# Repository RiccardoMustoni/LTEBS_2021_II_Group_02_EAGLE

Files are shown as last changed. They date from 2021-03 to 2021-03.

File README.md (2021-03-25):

# LTEBS_2021_II_Group_02_EAGLE

### Final Version 
The aim of the project is to design a PCB embedding the PSoC 5LP micro-controller in order to evaluate its performance and to determine if such uC is suitable for the project. The PCB embeds the CY8CKIT-059 kit, which will be soldered on male jumpers, and other additional components required to coduct the proper testing. 

The project consists in the design of a schematic, a board, and a library containing the necessary components. Design rules are added according to the technical specifications reported in the manufacturer website MDSrl.

### Project Folder 
The folder contains the schematic ("Group_02.sch") and the board ("Group_02.brd") used to create the final PCB.

### Library Folder 
The folder contains the library ("Group_02_Library.lbr") for the components TCA9546A and TMUX1208 with footprints, symbols and devices. 

### Design Rules Folder 
The folder contains the design rules ("Group_02.dru") according to the technical info on the manufacturer website. 

### Contributors 

Mancini Giorgia,
Mustoni Riccardo

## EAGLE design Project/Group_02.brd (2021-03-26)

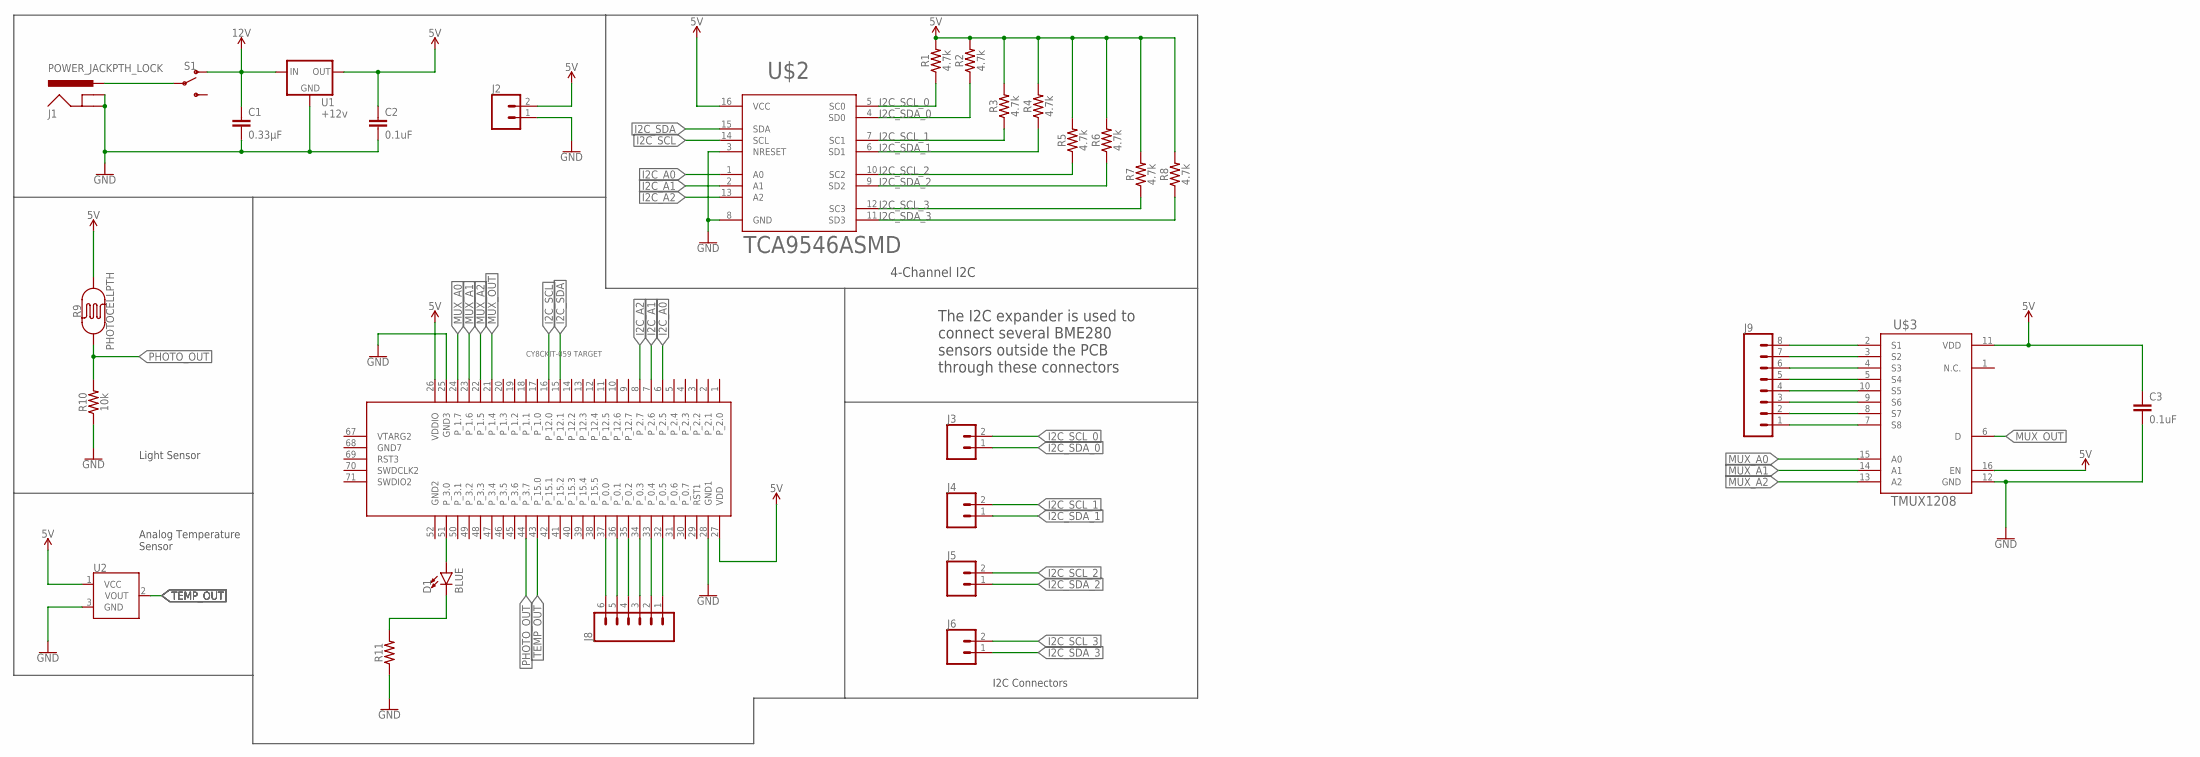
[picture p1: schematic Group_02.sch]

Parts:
C1: 0.33µF; 0805
C2, C3: 0.1uF; CAP-PTH-SMALL-KIT
D1: BLUE; LED-1206
J1: POWER_JACKPTH_LOCK; POWER_JACK_PTH_LOCK
J2, J3, J4, J5, J6: CONN_02; 1X02
J8: CONN_06LOCK; 1X06_LOCK
J9: CONN_08LOCK; 1X08_LOCK
R1, R2, R3, R4, R5, R6, R7, R8: 4.7k; 0603
R9: PHOTOCELLPTH; PHOTOCELL
R10: 10k; 0603
R11: AXIAL-0.3
S1: SWITCH-SPDT-PTH-11.6X4.0MM; SWITCH_SPDT_PTH_11.6X4.0MM
U1: +12v; TO-252
U2: TMP36GT9; TO-92
U$1: CY8CKIT-059_TARGET
U$2: TCA9546ASMD; TSSOP-16
U$3: TMUX1208; QFN-16

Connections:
5V: C2.1, C3.1, J2.2, R1.2, R2.2, R3.2, R4.2, R5.2, R6.2, R7.2, R8.2, R9.2, U1.2 (OUT), U2.1 (VCC), U$1.26 (VDDIO), U$1.27 (VDD), U$2.16 (VCC), U$3.11 (VDD), U$3.16 (EN)
12V: C1.1, S1.1 (O), U1.1 (IN)
GND: C1.2, C2.2, C3.2, J1.GND, J1.GNDBREAK, J2.1, R10.1, R11.P$1 (1), U1.3 (GND), U2.3 (GND), U$1.25 (GND3), U$1.28 (GND1), U$2.3 (NRESET), U$2.8 (GND), U$3.12 (GND)
I2C_A0: U$1.6 (P_2.5), U$2.1 (A0)
I2C_A1: U$1.7 (P_2.6), U$2.2 (A1)
I2C_A2: U$1.8 (P_2.7), U$2.13 (A2)
I2C_SCL: U$1.16 (P_12.0), U$2.14 (SCL)
I2C_SCL_0: J3.2, R1.1, U$2.5 (SC0)
I2C_SCL_1: J4.2, R3.1, U$2.7 (SC1)
I2C_SCL_2: J5.2, R5.1, U$2.10 (SC2)
I2C_SCL_3: J6.2, R7.1, U$2.12 (SC3)
I2C_SDA: U$1.15 (P_12.1), U$2.15 (SDA)
I2C_SDA_0: J3.1, R2.1, U$2.4 (SD0)
I2C_SDA_1: J4.1, R4.1, U$2.6 (SD1)
I2C_SDA_2: J5.1, R6.1, U$2.9 (SD2)
I2C_SDA_3: J6.1, R8.1, U$2.11 (SD3)
MUX_A0: U$1.24 (P_1.7), U$3.15 (A0)
MUX_A1: U$1.23 (P_1.6), U$3.14 (A1)
MUX_A2: U$1.22 (P_1.5), U$3.13 (A2)
MUX_OUT: U$1.21 (P_1.4), U$3.6 (D)
unnamed: J1.PWR, S1.2
unnamed: J8.1, U$1.32 (P_0.5)
unnamed: J8.2, U$1.33 (P_0.4)
unnamed: J8.3, U$1.34 (P_0.3)
unnamed: J8.4, U$1.35 (P_0.2)
unnamed: J8.5, U$1.36 (P_0.1)
unnamed: J8.6, U$1.37 (P_0.0)
unnamed: D1.A, U$1.51 (P_3.0)
unnamed: D1.C, R11.P$2 (2)
unnamed: J9.8, U$3.2 (S1)
unnamed: J9.7, U$3.3 (S2)
unnamed: J9.6, U$3.4 (S3)
unnamed: J9.5, U$3.5 (S4)
unnamed: J9.4, U$3.10 (S5)
unnamed: J9.3, U$3.9 (S6)
unnamed: J9.2, U$3.8 (S7)
unnamed: J9.1, U$3.7 (S8)
PHOTO_OUT: R9.1, R10.2, U$1.44 (P_3.7)
TEMP_OUT: U2.2 (VOUT), U$1.43 (P_15.0)

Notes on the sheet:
Light Sensor
Analog Temperature Sensor
I2C Connectors
The I2C expander is used to connect several BME280 sensors outside the PCB through these connectors
4-Channel I2C

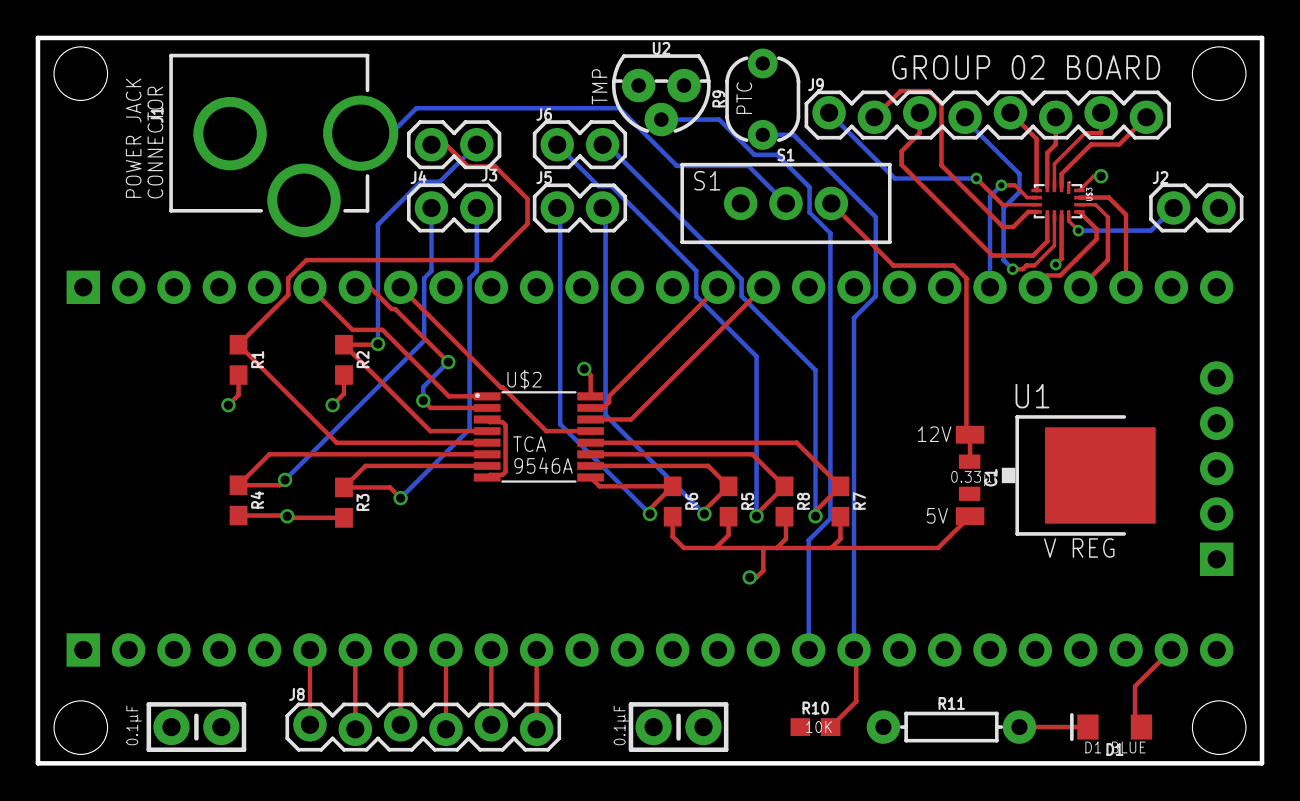
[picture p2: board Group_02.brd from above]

Board: 2 copper layers, 68.6 x 40.6 mm, 29 parts (1 on the bottom side), 39 nets.

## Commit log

2021-03-18 Mux schematico centrato
2021-03-19 Inizio Schematico
    [Group_02.sch]
2021-03-19 Aggiornamento schematico
    [Group_02.sch]
2021-03-19 Completamento schematico con tca
    [Group_02.sch]
2021-03-19 Creato albero directories
    [Group_02.sch]
2021-03-20 Ora è completo
    [Group_02.sch]
2021-03-20 PCB completa
    [Group_02.brd, Group_02.sch]
2021-03-21 Posizionamento holes
    [Group_02.brd]
2021-03-21 Aggiornamento M3 holes
    [Group_02.brd]
2021-03-21 Routing width 10 mils
    [Group_02.brd]
2021-03-21 Ancora wire width 10 mils
    [Group_02.brd]
2021-03-21 Pulizia cavi
    [Group_02.brd]
2021-03-22 Tutti i cavi a 10 mils
    [Group_02.brd]
2021-03-22 Correzione design rules ed errori in board
    [Group_02.brd]
2021-03-22 Completamento collegamenti schematico
    [Group_02.brd, Group_02.sch]
2021-03-22 Correzioni tracce board
    [Group_02.brd]
2021-03-22 Completamento board
    [Group_02.brd, Group_02.sch]
2021-03-23 Ottimizzazione dimensioni board
    [Group_02.brd]
2021-03-23 Completamento board super ridotta
    [Group_02.brd]
2021-03-23 Progetto board super ridotta
    [Group_02.brd]
2021-03-24 Piccole modifiche e spostamenti
    [Group_02.brd]
2021-03-24 Aggiustamento posizionamento pin
    [Group_02.brd]
2021-03-25 File completi
    [Group_02.brd]
2021-03-25 Aggiunta isolamento
    [Group_02.brd]
2021-03-25 Isolamento bottom layer
    [Group_02.brd]
2021-03-26 aggiornamento design rules
    [Group_02.brd]
2021-03-26 rotazione power jack
    [Group_02.brd]
2021-03-26 file finali
    [Group_02.brd]
2021-03-26 Final Version
    [Group_02.brd]

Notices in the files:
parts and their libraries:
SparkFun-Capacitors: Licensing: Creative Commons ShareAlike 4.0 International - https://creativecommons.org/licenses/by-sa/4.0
